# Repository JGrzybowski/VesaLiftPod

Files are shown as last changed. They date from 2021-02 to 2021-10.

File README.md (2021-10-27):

# VESA LiftPod Mount 
This project allows to add 4 LiftPod arms to your VESA mounted monitors - one in each direction.
To generate an custom STL file you will need to install OpenScad and tweek the parameters depending on your needs. Thingiverse's customizer might also allow to do this, but it's availability status is questionable at least.
# Parameters Description

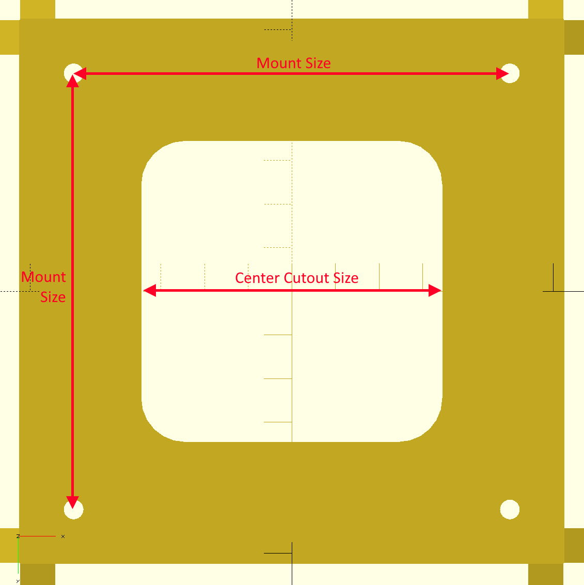
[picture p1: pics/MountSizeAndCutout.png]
Mount size and cutout

### Mount Size 
You can choose from 2 VESA mount standards:
- 100x100 (default)
- 75x75

### Center Cutout Size 
The middle of the Lift Pod VESA Mount is empty to accomodate the arm of your VESA arm/stand. The more you remove the faster will be the print and the easier the mounting process will be.

Remember to adjust this valuess esspecially if you want to use the 75x75 standard. The recomended values are:
- 94 for 100x100 standard
- 68 for 75x75

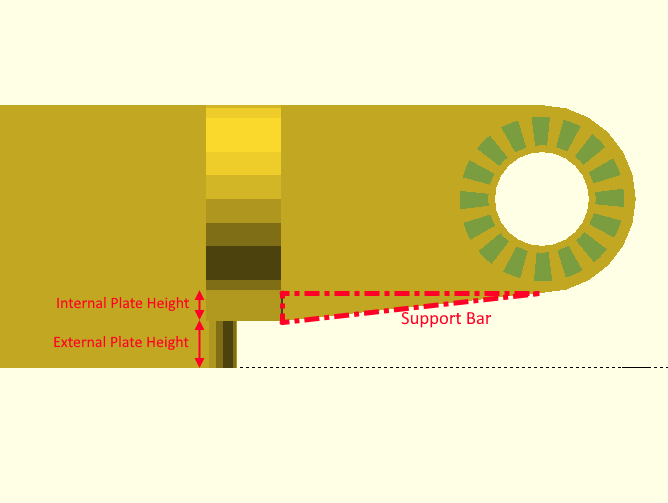
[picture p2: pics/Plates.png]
Plates heights and support bars


### External Plate Height 
It's the height of the part that will be put directly against the monitor.
If your monitor has an indent for VESA mount use the depth of the indent plus 1-2mm.

If VESA mount in your monitor is flush with the back of it you can use 0mm to use less plastic.

### Internal Plate Height
This is the thickness of the plate that has the Lift Pod arms attached to it. 

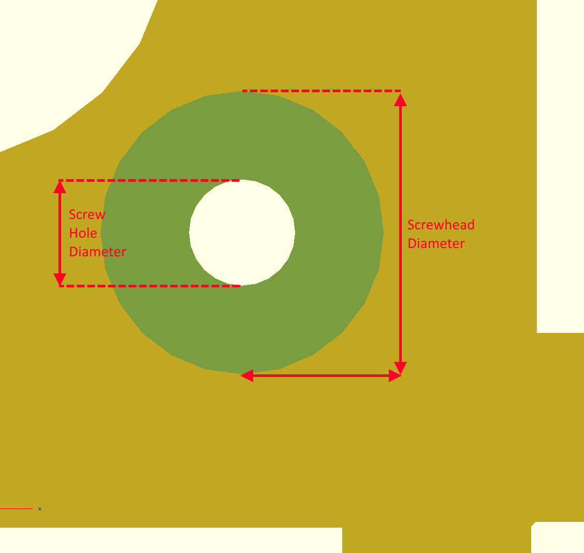
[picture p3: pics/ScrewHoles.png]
Screwhole dimentions


### Screw Head Diamiter
Size of the cutout for the washer or the screwhead.

If you use multibit screwdriver it is wise to leave some more space for the scredrivers's rod. 12mm worked for me just fine, but your milage may wary.

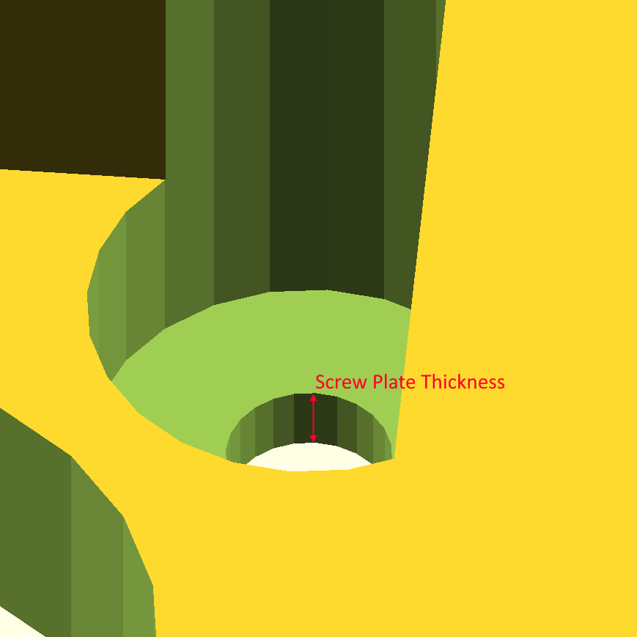
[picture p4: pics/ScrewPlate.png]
Screw plate thickness

### Screw Plate Thickness
Thickness of the mount under the screw. External and Internal Plates thickness does not affect the thickness of the Screw Plate. 

Bear in mind that the thicker the plate the shorter part of the VESA screw is inside the monitor. Please, check if most of the screw will be still inside the monitor before you start printing. 

Best way to do that is to measure the length of the VESA mount screw that came with your monitor or mounting arm and subtract from it the Screw Plate Thickness and thickness of your VESA arm/stand plate. If it is more than two thirds of the length then will probably be fine. Once more, please test the installed Lift Pod arm with the monitor on minimal height to prevent serious damage to the screen.

### Support Bars 
These are mainly to ease a bit the printing process. Depending on your print settings these can help or hinder with prinitng - it depends for example - wether you use External Plate or not.

Experiment with your print settings and check what works best with your slicer/printer.

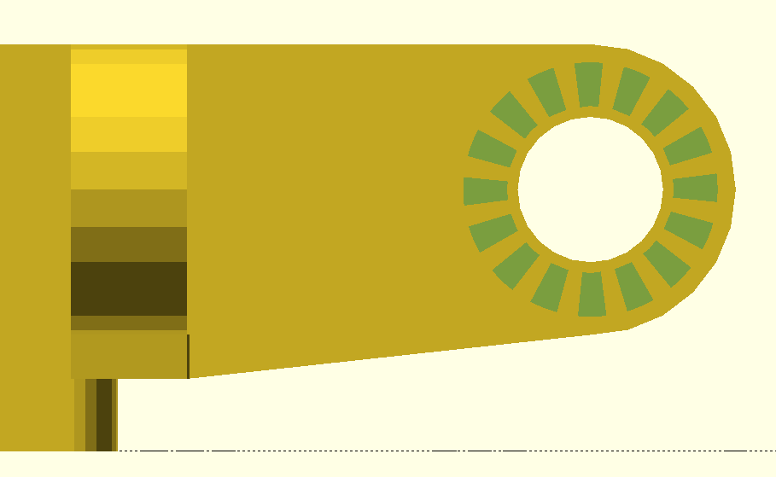
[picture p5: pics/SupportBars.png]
With Suppor Bars

With support bars

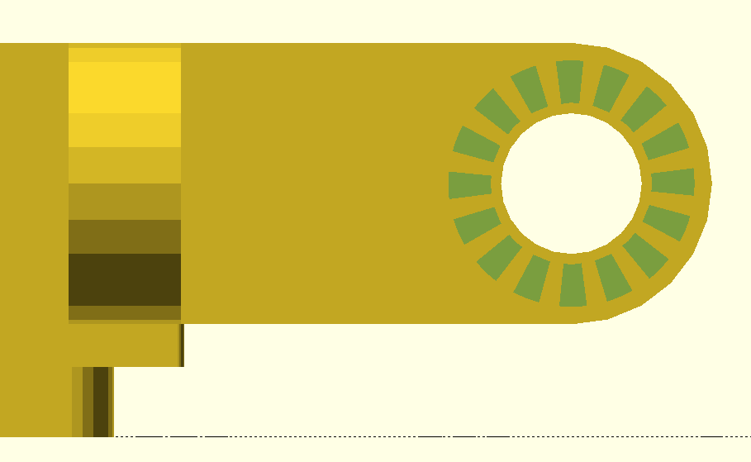
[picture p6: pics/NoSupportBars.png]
Without Suppor Bars

Without support bars

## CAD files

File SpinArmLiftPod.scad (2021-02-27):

include <lib/roundedcube.scad>;
include <lib/LiftPod.scad>;
include <lib/shortcuts.scad>;

/* [ Horizontal ] */
Horizontal_connector_length = 60; 
Horizontal_connector_width = "Socket_spacing_arms"; //[Socket_spacing_base : Base plate distance, Socket_spacing_arms : Middle Arms / B extender arms distance, Socket_spacing_arms_inner : Inner Arms / A extender arms distance ]
BaseMountSocketsInside = Horizontal_connector_width == "Socket_spacing_arms_inner"; 

/* [ Vertical ] */
Vertical_connector_length = 50;
Vertical_connector_offset = 30;
Vertical_connector_width = "Socket_spacing_arms"; //[Socket_spacing_base : Base plate distance, Socket_spacing_arms : Middle Arms / B extender arms distance, Socket_spacing_arms_inner : Inner Arms / A extender arms distance ]
RotatedMountSocketsInside = Vertical_connector_width == "Socket_spacing_arms_inner"; 

/* [Hidden] */
// Change these values only if you know what you are doing, hexagonal screwhead sockets on the outside of arm are probably not what you want.
BaseMountSocketsOutside = false; 
RotatedMountSocketsOutside = false;

BaseMountWidth = (Horizontal_connector_width == "Socket_spacing_base") ? Socket_spacing_base
               : (Horizontal_connector_width == "Socket_spacing_arms") ? Socket_spacing_arms
               : (Horizontal_connector_width == "Socket_spacing_arms_inner") ? Socket_spacing_arms_inner : 0;

RotatedMountWidth = (Vertical_connector_width == "Socket_spacing_base") ? Socket_spacing_base
                  : (Vertical_connector_width == "Socket_spacing_arms") ? Socket_spacing_arms
                  : (Vertical_connector_width == "Socket_spacing_arms_inner") ? Socket_spacing_arms_inner : 0;

// Default values of those are quite good to not to mess with them
Vertical_arm_length = RotatedMountWidth + Vertical_connector_offset + Socket_w;

module spin_arm(arms_l, base_l){

    joint_round = Socket_w/2;
    joint_thickness = Socket_w;

    tx( BaseMountWidth/2) ry(-90) liftPodHalfArm(arms_l, BaseMountSocketsInside ? SCREWHEAD : LOCKING_SOCKET, BaseMountSocketsOutside ? SCREWHEAD : LOCKING_SOCKET);
    tx(-BaseMountWidth/2) ry( 90) liftPodHalfArm(arms_l, BaseMountSocketsInside ? SCREWHEAD : LOCKING_SOCKET, BaseMountSocketsOutside ? SCREWHEAD : LOCKING_SOCKET);

    ty(arms_l/2) 
        roundedcube([BaseMountWidth+Socket_w, joint_thickness, Socket_d], radius=joint_round, center=true);
    
    base_bars_h = Vertical_connector_length;
    base_thickness = Socket_w;
    tx(BaseMountWidth/2) ty(arms_l/2+base_l/2-joint_round){
        roundedcube([base_thickness, base_l, Socket_d], radius = joint_round, center = true);
        ty((base_l-RotatedMountWidth)/2-joint_round) tx(base_bars_h/2+base_thickness/2-joint_round/2){ 
            ty( RotatedMountWidth/2) rx( 90) rz(90) liftPodHalfArm(base_bars_h+joint_round, RotatedMountSocketsInside ? SCREWHEAD : LOCKING_SOCKET, RotatedMountSocketsOutside ? SCREWHEAD : LOCKING_SOCKET);
            ty(-RotatedMountWidth/2) rx(-90) rz(90) liftPodHalfArm(base_bars_h+joint_round, RotatedMountSocketsInside ? SCREWHEAD : LOCKING_SOCKET, RotatedMountSocketsOutside ? SCREWHEAD : LOCKING_SOCKET);
        }
    }

    trapezoid = [
        [   -Socket_w/2, arms_l/2],
        [   +Socket_w/2, arms_l/2],
        [   BaseMountWidth/2, arms_l+45 ],
        [   BaseMountWidth/2, arms_l+45+Socket_w*1.75 ]
    ];
            
     trapezoid2 = [
        [   -Socket_w/2, arms_l/2],
        [   +Socket_w/2, arms_l/2],
        [   BaseMountWidth/2-Socket_w/2, base_l+8-Socket_w*0.25 ],
        [   BaseMountWidth/2-Socket_w/2, base_l+8+Socket_w*1.75 ]
    ];

    linear_extrude(height = Socket_d, center = true, convexity = 10) polygon(trapezoid); 
    linear_extrude(height = Socket_d, center = true, convexity = 10) polygon(trapezoid2); 
}

spin_arm(Horizontal_connector_length, Vertical_arm_length);

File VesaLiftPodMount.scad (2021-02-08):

include <lib/LiftPod.scad>;
include <lib/roundedcube.scad>;
include <lib/lockingSlot.scad>;
include <lib/shortcuts.scad>;

/* [VESA Mount] */

//Mount standard
Mount_Size = 100; // [ 100:100x100, 75:75x75 ]

// Height of the part of VESA plate outside the mount
External_Plate_Height = 5;  

// Height of the part of VESA plate inside the mount - provides more rigidity and which connects VESA Mount with sockets
Internal_Plate_Height = 3;

// VESA mount screw thread diameter
Screw_Thread_Diameter = 4.5; 

// VESA mount screw Head or Washer diameter
Screw_Head_Diameter = 12;

// Height of the plate under the screw
Screw_plate_Thickness = 2;

/* [General] */

// Size of the cutout in the center of the Mount - reduces required matrial
Center_Cutout_Size = 94;

// Should LiftPod mounts have additional support(angle depends on the height of the external plate)
Support_Bars = true; //[on:true, off:false]

// ------------------------------------------------------
mount = Mount_Size;

vesa_h = External_Plate_Height; 
lift_pod_h = Internal_Plate_Height;

screw_size = Screw_Thread_Diameter; 
screw_head_size = Screw_Head_Diameter;
screw_plate_h = Screw_plate_Thickness;

cutout = Center_Cutout_Size;

module Vesa(mount,  vesa_h, lift_pod_h, inside_cutout){
    plate_size = 125;
    bar_length = 200;

    module mount_holes(mount = mount, d, h, z = 0){
        for(x =[-mount/2, mount/2])
        for(y =[-mount/2, mount/2])
            t([ x, y, z+h/2]) cylinder(d = d, h = h, center = true);
    }

    module bar_support(h, top_w, bottom_w){
        trapezoid = [
            [   -top_w/2,  h/2],
            [-bottom_w/2, -h/2],
            [ bottom_w/2, -h/2],
            [    top_w/2,  h/2]
        ];
            
        rx(90) linear_extrude(height = Socket_w, center = true, convexity = 10) polygon(trapezoid);
    }  

    vesa_z     = vesa_h/2;
    plate_z    = vesa_h+lift_pod_h/2-0.001;
    bars_z     = vesa_h+lift_pod_h+Socket_d/2-0.001;
    supports_z = plate_z;

    difference(){
        union(){
            //Vesa Plate
            tz(vesa_z) roundedcube([mount+15,mount+15,vesa_h], true, radius = 3);
            
            //Bars Mount Plate
            tz(plate_z) roundedcube([plate_size, plate_size, lift_pod_h], center = true);

            //Mount Bars
            t([ Socket_spacing_base/2,0,bars_z])        ry(90) liftPodArm(bar_length);
            t([-Socket_spacing_base/2,0,bars_z])        ry(90) liftPodArm(bar_length);
            t([0, Socket_spacing_base/2,bars_z]) rz(90) ry(90) liftPodArm(bar_length);
            t([0,-Socket_spacing_base/2,bars_z]) rz(90) ry(90) liftPodArm(bar_length);

            //Mount Bars Supports
            if(Support_Bars) {
                tz(supports_z) {
                    ty(-Socket_spacing_base/2) bar_support(lift_pod_h, (bar_length-Socket_d), plate_size);
                    ty( Socket_spacing_base/2) bar_support(lift_pod_h, (bar_length-Socket_d), plate_size);
                    rz(90) {
                        ty(-Socket_spacing_base/2) bar_support(lift_pod_h, (bar_length-Socket_d), plate_size);
                        ty( Socket_spacing_base/2) bar_support(lift_pod_h, (bar_length-Socket_d), plate_size);
                    }
                }
            }
        }

        // Center cutout
        roundedcube([cutout,cutout,(vesa_h+lift_pod_h+Socket_d)*2], true, radius = 10);
        
        // Vesa Mount holes
        mount_holes(mount, screw_size, h=100, z=-10);
        mount_holes(mount, screw_head_size, h=100, z=screw_plate_h);
    }
}

Vesa(mount, vesa_h, lift_pod_h, cutout);

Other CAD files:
TiltArmLiftPod.scad

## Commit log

2020-12-28 Initial version
    [roundedcube.scad, shapesAndCuttingTools.scad, shortcuts.scad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]
2020-12-28 Simplified roundcube
    [roundedcube.scad]
2020-12-28 Simplified Vesa mount file
    [VesaLiftPodMount.scad]
2020-12-29 Commented code cleanup
    [VesaLiftPodMount.scad]
2020-12-30 Added extra support for lift pod mounting bars
    [VesaLiftPodMount.scad]
2020-12-30 Customizer support and code cleanup
    [VesaLiftPodMount.scad]
2020-12-30 Fix for 75x75 plate disconnected from the bars
    [VesaLiftPodMount.scad]
2020-12-30 Added better support for sockets
    [VesaLiftPodMount.scad]
2020-12-30 Comments and code cleanup
    [VesaLiftPodMount.scad]
2021-02-04 Simplified support bars
    [VesaLiftPodMount.scad]
2021-02-04 gitignore and publish script and project structure
    [VesaLiftPodMount.scad, shapesAndCuttingTools.scad]
2021-02-05 renamed washing.scad
    [VesaLiftPodMount.scad]
2021-02-05 Described Support_Bars
    [VesaLiftPodMount.scad]
2021-02-08 Separated LiftPod into another lib file
    [VesaLiftPodMount.scad]
2021-02-08 Vesa mount code cleanup
    [VesaLiftPodMount.scad]
2021-02-23 SpinArm for LiftPod initial version
    [SpinArmLiftPod.scad]
2021-02-24 Added hexagonal socket hole
2021-02-24 Added arms connectors width controls
    [SpinArmLiftPod.scad]
2021-02-27 Simplified customization and created parameters Json for spin arm
    [SpinArmLiftPod.scad]
2021-03-02 Renamed Spin Arm to Tilt Arm
    [TiltArmLiftPod.scad]
